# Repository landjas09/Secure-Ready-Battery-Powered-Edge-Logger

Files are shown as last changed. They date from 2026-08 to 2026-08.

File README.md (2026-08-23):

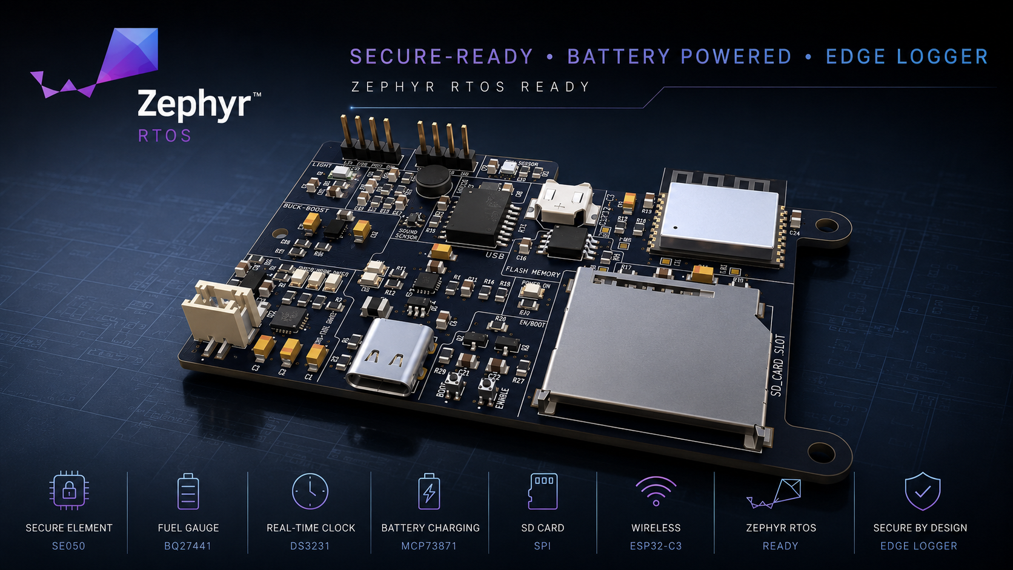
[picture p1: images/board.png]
ESP32-C3 Secure Edge Logger — assembled board


# Secure-Ready Battery-Powered Edge Logger

A custom ESP32-C3 hardware/firmware platform, developed across two revisions — from a general-purpose IoT sensor board into a battery-aware, timestamped, secure-ready edge data logger. Designed end-to-end in KiCad, ported to Zephyr RTOS.
This repository contains the full hardware design (schematics, PCB layout, BOM) for both revisions.

---

## Overview

The project began as the **IoT Development Board** (**Rev 1**) — a general-purpose ESP32-C3 sensor/data-logging platform: WiFi/BLE connectivity, environmental and ambient-light sensing, audio capture, local storage, and LiPo charging on a single compact PCB.

**Rev 2, the Secure-Ready Battery-Powered Edge Logger**, evolved that platform with a regulated buck-boost power stage holding 3.3V across the full LiPo discharge range, a battery fuel gauge with Kelvin current sensing, a battery-backed real-time clock for offline timestamping, and a hardware secure element for protected device identity and cryptographic key storage. The name change is deliberate, not cosmetic — it reflects the shift from a general-purpose development board to a system built around a specific mission: unattended, battery-aware, timestamped, secure-ready edge logging.

Both revisions share the same core sensing/storage/connectivity architecture; Rev 2 adds the hardware needed to take the board from *prototype* toward *deployable product*.

---

## Repository Structure

```
├── hardware/
│   ├── rev1/                     # IoT Development Board (original revision)
│   │   ├── README.md             # Full hardware documentation for Rev 1
│   │   └── ...                   # KiCad project, BOM, libraries
│   │
│   └── rev2/                     # Secure-Ready Battery-Powered Edge Logger (current revision)
│       ├── README.md             # Full hardware documentation for Rev 2
│       └── ...                   # KiCad project, BOM, libraries
│

│
└── README.md                     # This file
```

> Each revision is self-contained — its own KiCad project, its own Gerbers/BOM, and its own README with full component-level documentation, block diagrams, and design notes. Start here for the high-level picture, then go to the revision folder for detail.

---

## Hardware Revisions at a Glance

| | Rev 1 — IoT Development Board | Rev 2 — Secure Edge Logger |
|---|---|---|
| MCU | ESP32-C3-WROOM-02-H4 | ESP32-C3-WROOM-02-H4 |
| Power regulation | LM1117-3.3 linear regulator | TPS63802 buck-boost (regulated 3.3V across full LiPo range) |
| Battery charging | MCP73871 (charge + power-path) | MCP73871 (unchanged) |
| Battery state monitoring | Charge-status LEDs only | + BQ27441-G1A fuel gauge, 10mΩ Kelvin current sensing |
| Timekeeping | None (network time only) | + DS3231SN battery-backed RTC |
| Security | None | + NXP EdgeLock SE050E2 secure element |
| Storage | microSD + W25Q32 SPI NOR flash | microSD + W25Q32 SPI NOR flash (unchanged) |
| Sensing | BME280, TEMT6000X01, mic + MAX4466 preamp | Unchanged |
| Connectivity | USB-C, CP2102N USB-UART, OLED I²C header | Unchanged |
| Firmware target | Zephyr RTOS | Zephyr RTOS |

Full rationale for each Rev 2 change — including the buck-boost layout, Kelvin sensing wiring, and shared I²C bus considerations across five devices — is documented in [`hardware/rev2_secure-edge-logger/README.md`](hardware/rev2_secure-edge-logger/README.md).

---

## Design Evolution: The Engineering Behind Rev 1 → Rev 2

Rev 1 answered a narrower question: *can this sensing/connectivity architecture work on a single ESP32-C3 board?* It did — but running it as something closer to an actual field-deployed logger, rather than a bench prototype, surfaced four real limitations that Rev 1's architecture had no answer for. Rev 2 exists specifically to close those four gaps.

**1. The power rail wasn't guaranteed across the battery's actual operating range.**
The LM1117 is a linear regulator — it can only step *down*, and needs a few hundred millivolts of headroom above 3.3V to stay in regulation. A single-cell LiPo spends a meaningful portion of its discharge curve at or below that threshold, well before the cell is actually empty. In practice, that meant the system rail could sag or brown out with real battery capacity still remaining — the board would report "low battery" behavior driven by the regulator's limits, not the battery's. The **TPS63802 buck-boost** converter can step the rail up *or* down as needed, holding a stable 3.3V across the LiPo's full discharge range. The trade-off is real: an inductor-based switching regulator is a more complex layout than a 3-pin LDO (switching-node placement, input/output capacitor proximity), but it removes an artificial ceiling on usable battery capacity.

**2. Battery state was inferred, not measured.**
Rev 1's only battery-state signal was the MCP73871's charge-status LEDs — charging, charged, or power-good. That tells you the *charger's* state, not the battery's: no state-of-charge percentage, no remaining runtime estimate, no visibility into battery health over repeated cycles. For a device meant to log unattended in the field, "the LED is off" isn't useful data. The **BQ27441-G1A fuel gauge**, paired with a 10mΩ Kelvin-sensed shunt for accurate current measurement, gives the firmware real coulomb-counted state-of-charge and capacity data — the difference between guessing how much runtime is left and actually knowing.

**3. Timestamps depended on the network being present, and couldn't survive a real power interruption.**
The ESP32-C3 does have an internal RTC timer, and it runs independently of WiFi — but it has two limitations that make it unsuitable as the sole time source for an offline logger. First, it has no absolute time reference of its own; it only counts elapsed ticks, so it needs to be told the actual date/time at least once, which in Rev 1 meant NTP over WiFi. Second, and more importantly, it has no dedicated backup power domain — it's powered from the same rail as the rest of the chip, so a genuine power interruption (battery disconnected, fully depleted) resets it, and any subsequent logging either loses accurate timestamping or needs a full resync before it can be trusted again. That's a direct conflict with the point of an edge logger, which by definition needs to keep working — and keep accurate time — when disconnected or power-cycled. The **DS3231SN**, with its own dedicated backup supply, keeps ticking through main-power interruptions entirely independently of the ESP32-C3 and of network availability — log integrity no longer depends on the device staying connected or staying powered.

**4. There was no way to prove a device's identity, or protect anything it might need to keep secret.**
Rev 1 had no mechanism for device authentication at all. Any private key or credential would have had to live in the ESP32-C3's own flash — readable by anyone who can extract the chip's contents, meaning a physically compromised device could be cloned or impersonated with no way to detect it. The **SE050E2 secure element** generates and stores keys internally and performs signing/crypto operations without ever exposing key material to the application processor. This is explicitly a *hardware readiness* change, not a finished feature — the chip makes protected device identity possible; actual authentication behavior still has to be implemented and provisioned at the firmware level.

Taken together, Rev 1 — the **IoT Development Board** — validated *that the concept works*. Rev 2 — the **Secure-Ready Battery-Powered Edge Logger** — is the set of changes needed to start asking whether it could actually be *trusted and deployed*: accurate power delivery, real battery visibility, time integrity without a network, and a hardware root of trust. The rename reflects that shift, from a general platform to a system built for a specific job.

---

## Firmware

Both revisions target a common **Zephyr RTOS** board port (`iot_sensor_node_esp32c3`), built from scratch rather than as an overlay on an existing Espressif reference board — the SoC layer is inherited from Zephyr's existing ESP32-C3 support, with Devicetree, pinctrl, and Kconfig scoped to this board's actual hardware.

See [`zephyr/README.md`](https://github.com/landjas09/Zephyr-RTOS-Port/blob/db37eb44f9d1a81693981f7a8ff599a05c521f56/README.md) for the full board architecture, peripheral integration (I²C, SPI, ADC, UART, GPIO), debugging/OpenOCD setup, and the specific integration issues encountered and resolved during the port.

---

## Design Tools

- **Schematic capture & PCB layout:** KiCad 10
- **Electrical/design verification:** KiCad ERC & DRC
- **Firmware / board support:** Zephyr RTOS
- **Secure-element middleware:** NXP Plug & Trust (SE050E2)
- **Hardware configuration:** Silicon Labs Simplicity Studio / Xpress Configurator

---

## Where to Go Next

- **New to the project?** Start with [`hardware/rev1_iot-development-board/README.md`](hardware/rev1_iot-development-board/README.md) for the original, simpler architecture.
- **Interested in the current hardware?** Go to [`hardware/rev2_secure-edge-logger/README.md`](hardware/rev2_secure-edge-logger/README.md) for the full secure edge-logger design.
- **Interested in the firmware/RTOS side?** Go to [`zephyr/README.md`](https://github.com/landjas09/Zephyr-RTOS-Port/blob/db37eb44f9d1a81693981f7a8ff599a05c521f56/README.md) for the board port documentation.

---

## Acknowledgments

Board design informed by manufacturer reference designs and application notes from Espressif, Microchip, Texas Instruments, NXP, Analog Devices/Maxim, Silicon Labs, Bosch Sensortec, Winbond, and the Zephyr Project.

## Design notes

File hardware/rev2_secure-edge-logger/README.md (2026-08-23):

# Secure-Ready Battery-Powered Edge Logger — ESP32-C3

A custom-designed battery-powered edge logging platform built around the **ESP32-C3-WROOM-02**, evolved from the original IoT Development Board into a more complete embedded system with persistent timekeeping, hardware-backed security, battery-state monitoring, regulated battery operation, local storage, environmental sensing, ambient light sensing, audio capture, and USB-C programming/debug support. Designed end-to-end in **KiCad 10**, from schematic capture through PCB layout and routing.

---

## Overview

This board is a **secure-ready, battery-powered edge data-logging platform** — capable of acquiring sensor data, maintaining absolute time across power interruptions, storing data locally, monitoring its own battery state, and supporting hardware-protected device identity and cryptographic operations.

The ESP32-C3 remains the main processing and wireless controller, with critical system functions separated into dedicated hardware blocks: LiPo charging and power-path management (MCP73871), regulated buck-boost 3.3V conversion (TPS63802), battery fuel gauging (BQ27441-G1A), persistent real-time clock (DS3231SN), hardware-backed key storage (SE050E2), and local storage across microSD and external SPI flash.

**Applications:**
- Battery-powered environmental and acoustic edge logging
- Offline, timestamped sensor-data acquisition
- Secure-ready IoT edge nodes requiring protected device credentials
- Battery-aware embedded sensing platforms
- Zephyr RTOS hardware/driver development and validation

**Key design goals:**
- Reliable operation from both USB-C and a single-cell LiPo battery
- Regulated 3.3V operation across the full LiPo discharge range
- Battery charging, power-path management, and state-of-charge monitoring
- Persistent absolute time, independent of network availability
- Hardware support for protected device identity and cryptographic keys
- Local timestamped data logging through microSD and external SPI flash
- Environmental, ambient-light, and acoustic sensing
- USB-to-UART programming/debugging without an external serial adapter
- Shared I²C expansion with an external OLED header

---

## Block Diagram

```mermaid
flowchart LR
    USB[USB-C Connector<br/>SS-52400-002] --> ESD[ESD Protection<br/>USBLC6-2SC6]
    USB --> CHG[LiPo Charger / Power Path<br/>MCP73871-2CAI_ML]
    ESD --> UART[USB-UART Bridge<br/>CP2102N-Axx-xQFN20]
    UART <--> MCU[ESP32-C3-WROOM-02-H4]

    CHG --> REG[3.3V Buck-Boost<br/>TPS63802]
    REG --> MCU
    CHG --> LED1[Charge Status LEDs<br/>PG / STAT1 / STAT2]

    CHG <--> SHUNT[10 mΩ Kelvin Shunt]
    SHUNT <--> BAT[JST 1S LiPo Battery Connector]
    SHUNT --> GAUGE[BQ27441-G1A<br/>Fuel Gauge]
    BAT --> GAUGE

    MCU <-->|I2C| BME[BME280<br/>Temperature + Humidity + Pressure]
    MCU <-->|I2C| RTC[DS3231SN<br/>Battery-Backed RTC]
    MCU <-->|I2C| SE[SE050E2<br/>Secure Element]
    MCU <-->|I2C| GAUGE
    MCU <-->|I2C| OLED[OLED Display Header]

    MCU <-->|ADC| LDR[TEMT6000X01<br/>Ambient Light]
    MCU <-->|ADC| MIC[CMC-5042PF-AC + MAX4466EXK<br/>Microphone + Preamplifier]

    MCU <-->|SPI| FLASH[W25Q32JVSSIQ<br/>External SPI NOR Flash]
    MCU <-->|SPI| SD[GSD090012SEU<br/>microSD Card]

    RTC --> RTCBAT[RTC Backup Battery]

    MCU --> BOOT[BOOT / EN Buttons]
    MCU --> GPIO[GPIO18 / GPIO19 Breakout]
```

---

## Hardware Overview

### Power & Battery Management
| Component | Part Number | Function |
|---|---|---|
| USB-C Connector | SS-52400-002 | Main external power/data input |
| ESD Protection | USBLC6-2SC6 | Protects USB D+/D- from ESD transients |
| LiPo Charger / Power Path | MCP73871-2CAI_ML | Single-cell Li-Ion/LiPo charging and load-sharing/power-path management |
| 3.3V Regulator | TPS63802 | Buck-boost conversion for regulated 3.3V operation across the variable battery rail |
| Fuel Gauge | BQ27441-G1A | Battery voltage/current, state-of-charge, remaining-capacity, and health estimation |
| Current-Sense Resistor | 10 mΩ, 4-terminal Kelvin shunt | High-side charge/discharge current measurement for the BQ27441 |
| Battery Connector | JST 2-pin | Single-cell LiPo connection |
| Status Indicators | LED x3 | MCP73871 charging / charge-complete / power-good indication |

The MCP73871 controls the USB/battery power path exactly as in Rev 1 — powering the system while charging over USB, and switching seamlessly to battery when USB is removed.

The original **LM1117-3.3 linear regulator was replaced with a TPS63802 buck-boost converter**, since a single-cell LiPo spends most of its discharge curve below 3.3V toward the low end of its range — a linear regulator alone can't hold 3.3V once the input drops below it. The buck-boost stage keeps the 3.3V rail regulated whether the battery sits above or below that threshold.

The BQ27441-G1A measures charge/discharge current through a dedicated 10 mΩ Kelvin shunt inserted between the battery and the MCP73871's VBAT side, with dedicated SRP/SRN sense connections routed directly to the shunt's sense terminals to minimize measurement error.

### Timekeeping & Hardware Security
| Component | Part Number | Interface | Function |
|---|---|---|---|
| Real-Time Clock | DS3231SN | I²C | Battery-backed absolute time for timestamped logging |
| Secure Element | NXP EdgeLock SE050E2 | I²C | Hardware-protected key storage, device identity, signing, and cryptographic operations |

The DS3231SN provides absolute time independent of WiFi/network availability, retaining time through main-power interruptions via its own backup supply. Its **INT/SQW** output connects to **ESP32-C3 GPIO8** for alarm/square-wave functionality.

The SE050E2 provides the hardware foundation for a device root of trust — generating and storing private keys internally and performing cryptographic operations without ever exposing key material to the ESP32 application. Its presence makes the platform *secure-ready*; actual authentication/TLS/signing behavior still needs to be implemented at the firmware level.

### Core & Connectivity
| Component | Part Number | Function |
|---|---|---|
| MCU | ESP32-C3-WROOM-02-H4 | RISC-V, WiFi + BLE, main system controller |
| USB-UART Bridge | CP2102N-Axx-xQFN20 | USB-to-serial for programming/debugging |
| Flash Memory | W25Q32JVSSIQ | 32Mbit external SPI flash (firmware/config storage) |
| SD Card Socket | GSD090012SEU | microSD card slot (bulk data storage: logs, audio, images) |

Programming and debugging run over native USB via the CP2102N — USB-C → CP2102N → UART0 — with manual **BOOT** and **EN** pushbuttons as a direct hardware fallback.

### Sensors
| Component | Part Number | Interface | Function |
|---|---|---|---|
| Environmental Sensor | BME280 | I²C | Temperature, humidity, and barometric pressure |
| Ambient Light Sensor | TEMT6000X01 | Analog (ADC) | Ambient light intensity |
| Microphone Capsule | CMC-5042PF-AC | Analog | Electret condenser microphone |
| Mic Preamplifier | MAX4466EXK+T | Analog (ADC) | Adjustable-gain (25x–125x) microphone amplifier |

### User Interface / Expansion
- **BOOT** and **EN** pushbuttons for manual firmware flashing / reset
- **OLED display header** on the shared I²C bus
- **GPIO18 / GPIO19 breakout**, remaining available for alternate functions such as native USB/JTAG when not assigned by the application
- **GPIO8 is no longer spare** — it is now assigned to the DS3231SN's `INT/SQW` signal

---

## Shared Bus Architecture

**SPI bus** (microSD card + external SPI NOR flash, shared MOSI/MISO/SCLK, independent CS lines):
```
ESP32 MOSI ──┬──▶ microSD MOSI
             └──▶ W25Q32 MOSI

ESP32 MISO ──┬──◀ microSD MISO
             └──◀ W25Q32 MISO

ESP32 SCLK ──┬──▶ microSD SCLK
             └──▶ W25Q32 SCLK

ESP32 GPIO5  ───▶ microSD CS
ESP32 GPIO10 ───▶ W25Q32 CS
```

**I²C bus** (BME280, OLED header, DS3231SN, BQ27441-G1A, and SE050E2 — all sharing one SDA/SCL bus):
```
ESP32 GPIO4 / SDA ──┬── BME280
                    ├── OLED header
                    ├── DS3231SN
                    ├── BQ27441-G1A
                    └── SE050E2

ESP32 GPIO3 / SCL ──┬── BME280
                    ├── OLED header
                    ├── DS3231SN
                    ├── BQ27441-G1A
                    └── SE050E2
```

The bus uses a single shared pull-up network located near the BME280 — since every device sits on the same SDA/SCL nets, all five devices share the same pull-up pair rather than each getting its own. Routing is primarily linear, with a short branch/stub to the SE050E2. Bus speed is currently configured conservatively in the Zephyr board definition.

---

## Design Tools

- **Schematic capture & PCB layout:** KiCad 10
- **Simulation/verification:** KiCad ERC & DRC (Electrical Rules Checker / Design Rules Checker)
- **Firmware / board support:** Zephyr RTOS
- **Secure-element middleware:** NXP Plug & Trust, for SE050E2
- **Hardware config tools:** Silicon Labs Simplicity Studio / Xpress Configurator (for one-time CP2102N GPIO/TXT-RXT configuration)

The Zephyr board port was updated for the Rev 2 hardware to add: DS3231 RTC integration, BQ27441 fuel-gauge integration through Zephyr's sensor subsystem, SE050 I²C transport mapping for NXP Plug & Trust, and GPIO8 allocation for the RTC's `INT/SQW` line — alongside the existing BME280, ADC, SPI NOR, microSD, UART, and GPIO support carried over from Rev 1.

---

## Repository Structure

This is a native **KiCad 10** hierarchical project — keep the main project file, root schematic, PCB file, and every child schematic sheet together so the hierarchy resolves correctly when cloned.

```
├── rev2-secure-edge-logger.kicad_pro   # Main KiCad project file
├── rev2-secure-edge-logger.kicad_sch   # Root schematic sheet
├── rev2-secure-edge-logger.kicad_pcb   # PCB layout
│
├── ESP32-C3-02.kicad_sch               # Sub-sheet: MCU + core connectivity
├── sensors.kicad_sch                   # Sub-sheet: BME280, light sensor, mic/amp
├── userInterface.kicad_sch             # Sub-sheet: BOOT/EN buttons, OLED header, breakout
│
├── Libraries/                          # Custom footprints, symbols, and 3D models
├── BOM.csv                             # Bill of materials
├── fp-lib-table                        # Footprint library table
├── sym-lib-table                       # Symbol library table
```

> Lock files (`*.lck`), `.history/`, and `.git/` are local/version-control housekeeping and not part of the design itself.

---

## Known Issues & Design Notes

- **Power architecture change:** the original LM1117-3.3 LDO was replaced with a TPS63802 buck-boost converter, since the LiPo's voltage range crosses above and below 3.3V — a linear regulator alone can't hold the rail once the battery drops below it.
- **Buck-boost layout:** TPS63802 input/output capacitors and the 0.47µH inductor are placed close to the regulator, with short/wide switching-current paths, and the feedback network routed away from the switching nodes.
- **Fuel-gauge measurement:** BQ27441 SRP/SRN use Kelvin connections directly to the 10mΩ four-terminal shunt; battery-voltage sensing is taken from the battery side of the shunt.
- **Charging vs. gauging are separate concerns:** the MCP73871's status outputs (PG, STAT1, STAT2) indicate *charger* state, not battery percentage — state-of-charge and remaining-capacity estimation is handled entirely by the BQ27441.
- **I²C pull-ups:** the entire bus (5 devices) uses one shared pull-up pair. Any future external module added to the OLED header needs to account for this — extra pull-ups on that module would combine in parallel and lower the effective bus resistance.
- **RTC interrupt:** DS3231SN's `INT/SQW` is open-drain, connected to GPIO8 — pull-up behavior needs to match the final hardware/firmware configuration.
- **Secure element scope:** SE050E2 provides the hardware capability for key storage and cryptographic operations, but the board should only be described as "cryptographically secured" once firmware actually provisions and uses those functions — the chip alone doesn't make the system secure.
- **GPIO5 / ADC2 conflict** (carried over from Rev 1): GPIO5 is the ESP32-C3's only ADC2 channel and is unreliable while WiFi is active. Analog signals (microphone, light sensor) use ADC1 pins instead; GPIO5 itself is used here purely as a digital SPI chip-select, where this limitation doesn't apply.
- **CP2102N TXT/RXT indicator LEDs:** default to plain GPIO mode from the factory and require explicit configuration via Silicon Labs' Xpress Configurator to enable the TXT/RXT alternate function.
- **SD card DAT3/CS line** requires a pull-up resistor so the card initializes into SPI mode rather than native SD mode at power-up.

---

## Planned Additions

- **Enclosure design (SolidWorks)** — case built around the Rev 2 board's exported KiCad STEP file, with cutouts for the USB-C port, BOOT/EN buttons, status LEDs, SD card slot, and a light-transmissive window over the ambient light sensor.

---

## Evolution from Rev 1

**Rev 1 — IoT Development Board** established the base platform: ESP32-C3 WiFi/BLE processing, BME280 environmental sensing, ambient-light and acoustic sensing, microSD + SPI NOR storage, LiPo charging and power-path management, USB-UART programming/debugging, OLED/GPIO expansion, and the initial custom Zephyr board port.

**Rev 2** extends that base around four system-level additions:

| Requirement | Change |
|---|---|
| Persistent timekeeping | Added DS3231SN with backup supply and RTC alarm/square-wave on GPIO8 |
| Hardware-backed security | Added NXP EdgeLock SE050E2 for protected device identity, key storage, and signing |
| Battery-state observability | Added BQ27441-G1A with 10mΩ Kelvin current sensing for voltage/current/SOC/health |
| Battery-range power regulation | Replaced LM1117-3.3 with TPS63802 buck-boost to hold 3.3V across the full LiPo range |

The result is no longer a general-purpose IoT development board — the architecture is now built around autonomous, timestamped, battery-aware logging with hardware security readiness built in from the start.

---

## Acknowledgments

Board design informed by manufacturer reference designs and application notes from Espressif, Microchip, Texas Instruments, NXP, Analog Devices/Maxim, Silicon Labs, Bosch Sensortec, Winbond, and the Zephyr Project.

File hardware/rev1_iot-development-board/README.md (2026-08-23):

# Custom IoT Development Board — ESP32-C3

A custom-designed IoT development board built around the **ESP32-C3-WROOM-02**, featuring integrated LiPo battery charging, environmental sensing, ambient light sensing, audio capture, on-board storage (flash + SD card), and a USB-C interface with full USB-to-UART programming support. Designed end-to-end in **KiCad 10**, from schematic capture through PCB layout and routing.

---

## Overview

This board was designed as a general-purpose sensor/data-logging platform for IoT applications — combining wireless connectivity (WiFi/BLE via the ESP32-C3), multiple onboard sensors, local storage, and rechargeable battery power into a single compact PCB.

## Aplications
- IoT edge devices for environmental monitoring.
- Battery-powered data logging systems.
- Prototyping platform for ESP32-based projects.

**Key design goals:**
- Fully USB-C powered and rechargeable (no external charger required)
- Onboard environmental, light, and audio sensing
- Local data logging via SD card, with dedicated flash for firmware/configuration
- Standard USB-to-UART programming/debugging, no external programmer needed
- Expandable via an I²C OLED connector and a breakout header for spare GPIOs

---

## Block Diagram

```mermaid
flowchart LR
    USB[USB-C Connector<br/>SS-52400-002] --> ESD[ESD Protection<br/>USBLC6-2SC6]
    USB --> CHG[LiPo Charger<br/>MCP73871-2CAI_ML]
    ESD --> UART[USB-UART Bridge<br/>CP2102N-Axx-xQFN20]
    UART <--> MCU[ESP32-C3-WROOM-02-H4]

    CHG --> BAT[JST LiPo Battery Connector]
    CHG --> REG[3.3V Regulator<br/>LM1117MPX-3.3]
    REG --> MCU
    CHG --> LED1[Charge Status LEDs]

    MCU <-->|I2C| BME[BME280<br/>Humidity + Pressure]
    MCU <-->|ADC| LDR[TEMT6000X01<br/>Ambient Light]
    MCU <-->|ADC| MIC[CMC-5042PF-AC + MAX4466EXK<br/>Mic + Amplifier]
    MCU <-->|SPI| FLASH[W25Q32JVSSIQ<br/>External Flash]
    MCU <-->|SPI| SD[GSD090012SEU<br/>microSD Card]
    MCU <-->|I2C| OLED[OLED Display Header]

    MCU --> BOOT[BOOT / EN Buttons]
    MCU --> GPIO[Spare GPIO Breakout]
```

---

## Hardware Overview

### Power Subsystem
| Component | Part Number | Function |
|---|---|---|
| USB-C Connector | SS-52400-002 | Main power/data input |
| ESD Protection | USBLC6-2SC6 | Protects USB D+/D- from ESD transients |
| LiPo Charger IC | MCP73871-2CAI_ML | Single-cell Li-Ion/LiPo charge management with power-path support |
| Voltage Regulator | LM1117MPX-3.3_NOPB | Regulates system rail to 3.3V |
| Battery Connector | JST 2-pin | Single-cell LiPo battery input |
| Status Indicators | LED x3 | Charging / Charged / Power-Good status |

The MCP73871's integrated power-path management allows the board to run directly from USB power while simultaneously charging the battery, and seamlessly switches to battery power when USB is disconnected — with no interruption to the system rail.

### Core & Connectivity
| Component | Part Number | Function |
|---|---|---|
| MCU | ESP32-C3-WROOM-02-H4 | RISC-V, WiFi + BLE, main system controller |
| USB-UART Bridge | CP2102N-Axx-xQFN20 | USB-to-serial for programming/debugging |
| Flash Memory | W25Q32JVSSIQ | 32Mbit external SPI flash (firmware/config storage) |
| SD Card Socket | GSD090012SEU | microSD card slot (bulk data storage: logs, audio, images) |

Programming and debugging are handled over native USB via the CP2102N, with automatic bootloader entry through a DTR/RTS-driven transistor reset circuit, plus manual BOOT and EN pushbuttons as a hardware fallback.

### Sensors
| Component | Part Number | Interface | Function |
|---|---|---|---|
| Environmental Sensor | BME280 | I²C | Humidity, barometric pressure, temperature |
| Ambient Light Sensor | TEMT6000X01 | Analog (ADC) | Ambient light intensity |
| Microphone Capsule | CMC-5042PF-AC | Analog | Electret condenser microphone |
| Mic Preamplifier | MAX4466EXK+T | Analog (ADC) | Adjustable-gain (25x–125x) microphone amplifier |

### User Interface / Expansion
- **BOOT** and **EN** pushbuttons for manual firmware flashing / reset
- **OLED display header** (I²C, 4-pin) for an external SSD1306-style display
- **Breakout header** exposing spare GPIOs (GPIO8, GPIO18, GPIO19) plus 3.3V/GND for future expansion

---

## Shared Bus Architecture

**SPI bus** (SD card + external flash, daisy-chained MOSI/MISO/SCLK, independent CS lines):
```
ESP32 MOSI ──┬──▶ SD Card MOSI ──▶ Flash MOSI
ESP32 MISO ──┼──◀ SD Card MISO ──◀ Flash MISO
ESP32 SCLK ──┴──▶ SD Card SCLK ──▶ Flash SCLK
ESP32 CS1  ─────▶ SD Card CS (dedicated)
ESP32 CS2  ─────▶ Flash CS (dedicated)
```

**I²C bus** (BME280 + OLED header, shared SDA/SCL with pull-ups):
```
ESP32 SDA ──┬──▶ BME280 SDA
            └──▶ OLED SDA
ESP32 SCL ──┬──▶ BME280 SCL
            └──▶ OLED SCL
```

---

## Design Tools

- **Schematic capture & PCB layout:** KiCad 10
- **Simulation/verification:** KiCad ERC & DRC (Electrical Rules Checker / Design Rules Checker)
- **Firmware:** successfully migrated to **Zephyr RTOS**
- **Hardware config tools:** Silicon Labs Simplicity Studio (for one-time CP2102N GPIO/TXT-RXT configuration)

---

## Repository Structure

This is a native **KiCad 10** project — the schematic is split hierarchically across multiple sheets, with sensors and user-interface elements broken out into their own sub-sheet files for readability.

```
├── IOT DEV BOARD.kicad_pro       # Main KiCad project file
├── IOT DEV BOARD.kicad_sch       # Root schematic sheet
├── IOT DEV BOARD.kicad_pcb       # PCB layout
├── ESP32-C3-02.kicad_sch         # Sub-sheet: MCU + core connectivity
├── sensors.kicad_sch             # Sub-sheet: BME280, light sensor, mic/amp
├── userInterface.kicad_sch       # Sub-sheet: BOOT/EN buttons, OLED header, breakout
│
├── ESP32_IOT_BOARD_GERBER/       # Exported Gerber/drill files for fabrication
├── Libraries/                    # Custom footprints and symbols
├── BOM.csv                       # Bill of materials
├── fp-lib-table                  # Footprint library table
├── sym-lib-table                 # Symbol library table
└── output.json                   # Exported netlist/data
```

> Lock files (`*.lck`), `.history/`, and `.git/` are local/version-control housekeeping and not part of the design itself.

---

## Known Issues & Design Notes

- **GPIO5 / ADC2 conflict:** GPIO5 is the ESP32-C3's only ADC2 channel, and ADC2 is unreliable while WiFi is active (and affected by a known silicon errata on some chip revisions). Analog signals (e.g. microphone, light sensor) must use **ADC1 pins (GPIO0–GPIO4)** instead.
- **CP2102N TXT/RXT indicator LEDs:** these pins default to plain GPIO mode from the factory and do **not** blink out of the box — they must be explicitly configured via Silicon Labs' **Xpress Configurator** (Simplicity Studio) to enable the TXT/RXT alternate function.
- **CP2102N QFN20 package** does not expose a physical DTR pin — DTR emulation for the auto-reset circuit is handled via a reconfigured spare GPIO, not a dedicated pin.
- **SD card DAT3/CS line** requires a pull-up resistor to guarantee the card boots into SPI mode rather than native SD mode at power-up.

---

## Planned Additions

- **DS3231SN** real-time clock (I²C) for accurate timestamping of logged sensor data, independent of network time availability.
- **Enclosure design (SolidWorks)** — case built around the board's exported KiCad STEP file, with cutouts for the USB-C port, BOOT/EN buttons, status LEDs, SD card slot, and a light-transmissive window over the ambient light sensor.

---

## Acknowledgments

Board design informed by manufacturer reference designs and application notes from Microchip, Silicon Labs, Espressif, and Winbond.

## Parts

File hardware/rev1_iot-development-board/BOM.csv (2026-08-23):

Reference | Qty | Value | Footprint | MANUFACTURER | Description
VR1 | 1 | LM1117MPX-3.3_NOPB | ESP32Footprints:VREG_LM1117MPX-3.3 | Texas Instruments | 800-mA 15-V linear voltage regulator
U7 | 1 | MAX4466EXK | ESP32Footprints:SOT65P210X110-5N |  | Amplifier IC 1-Channel (Mono) Class AB SC-70-5
U6 | 1 | BME280 | ESP32Footprints:PSON65P250X250X100-8N |  | Board Mount Humidity Sensors MEMS humidity, pressure and temperature sensor
U5 | 1 | USBLC6-2SC6 | Package_TO_SOT_SMD:SOT-23-6 |  | Very low capacitance ESD protection diode, 2 data-line, SOT-23-6
U4 | 1 | W25Q32JVSSIQ | ESP32Footprints:SOIC127P790X216-8N |  | FLASH - NOR Memory IC 32Mb (4M x 8) SPI - Quad I/O 133 MHz 8-SOIC
U3 | 1 | ESP32-C3-WROOM-02-H4 | ESP32Footprints:MODULE_ESP32-C3-WROOM-02-H4 |  | WiFi Modules (802.11) (Engineering Samples) SMD module, ESP32-C3, 4MB SPI flash, PCB antenna, -40 C +105 C
U2 | 1 | CP2102N-Axx-xQFN20 | Package_DFN_QFN:SiliconLabs_QFN-20-1EP_3x3mm_P0.5mm_EP1.8x1.8mm |  | USB to UART master bridge, QFN-20
U1 | 1 | MCP73871-2CAI_ML | ESP32Footprints:QFN50P400X400X100-21N | Microchip Corp. | Microchip MCP73871-2CAI/ML, Battery Charge Controller, 1000mA, 20-Pin QFN | Microchip Technology Inc. MCP73871-2CAI/ML
TP5 | 1 | TestCLK | TestPoint:TestPoint_Pad_1.0x1.0mm |  | test point
TP4 | 1 | TestCS | TestPoint:TestPoint_Pad_1.0x1.0mm |  | test point
TP3 | 1 | TestSD | TestPoint:TestPoint_Pad_1.0x1.0mm |  | test point
TP2 | 1 | TestMOSI | TestPoint:TestPoint_Pad_1.0x1.0mm |  | test point
TP1 | 1 | TestMISO | TestPoint:TestPoint_Pad_1.0x1.0mm |  | test point
S2 | 1 | ENABLE | TL3305AF260QG:SW_TL3305AF260QG | E-Switch | Tactile Switch SPST-NO Top Actuated Surface Mount
S1 | 1 | BOOT | TL3305AF260QG:SW_TL3305AF260QG | E-Switch | Tactile Switch SPST-NO Top Actuated Surface Mount
R25,R26 | 2 | 2k | Resistor_SMD:R_0805_2012Metric |  | Resistor
R23,R24 | 2 | 1M | Resistor_SMD:R_0805_2012Metric |  | Resistor
R22 | 1 | 10k | Resistor_SMD:R_0805_2012Metric |  | Resistor
R20,R21 | 2 | 4.7k | Resistor_SMD:R_0805_2012Metric |  | Resistor
R19 | 1 | 100K | Resistor_SMD:R_0805_2012Metric |  | Resistor
R15,R16,R17,R18 | 4 | 50 | Resistor_SMD:R_0805_2012Metric |  | Resistor
R14 | 1 | 47K5 | Resistor_SMD:R_0805_2012Metric |  | Resistor
R13 | 1 | 22K1 | Resistor_SMD:R_0805_2012Metric |  | Resistor
R7,R8,R9,R10,R11,R12 | 6 | 470 | Resistor_SMD:R_0805_2012Metric |  | Resistor
R6 | 1 | 20K | Resistor_SMD:R_0805_2012Metric |  | Resistor
R5 | 1 | 2K | Resistor_SMD:R_0805_2012Metric |  | Resistor
R3,R4 | 2 | 5K1 | Resistor_SMD:R_0805_2012Metric |  | Resistor
R2,R27,R28,R29,R30,R31 | 6 | 10K | Resistor_SMD:R_0805_2012Metric |  | Resistor
R1 | 1 | 1k | Resistor_SMD:R_0805_2012Metric |  | Resistor
Q2,Q3 | 2 | BC817 | Package_TO_SOT_SMD:SOT-23 |  | 0.8A Ic, 45V Vce, NPN Transistor, SOT-23
Q1 | 1 | TEMT6000X01 | ESP32Footprints:TRANS_TEMT6000X01 | VISHAY | Phototransistors 570nm Top View 1206 (3216 Metric)
MK1 | 1 | CMC-5042PF-AC | ESP32Footprints:CUI_CMC-5042PF-AC | CUI INC | 6.0 mm, Omnidirectional, PCB Mount, 2.0 Vdc, Electret Condenser Microphone
LED3 | 1 | LTST-C170TBKT | ESP32Footprints:LEDC2012X120N |  | LED,SMD,0805,Blue,28mcd,130deg
LED2,LED6 | 2 | LTST-C170GKT | ESP32Footprints:LEDC2012X120N |  | LED,SMD,0805,Green,6mcd,130deg Lite-On LTST-C170GKT, CHIPLED 0805 Series Green LED, 569 nm 2012 (0805), Rectangle Lens SMD package
LED1,LED4,LED5 | 3 | LTST-C170KRKT | ESP32Footprints:LEDC2012X120N |  | Standard LEDs - SMD Red Clear 631nm
J5 | 1 | Conn_01x05_Pin | Connector_PinHeader_2.54mm:PinHeader_1x05_P2.54mm_Vertical |  | Generic connector, single row, 01x05, script generated
J4 | 1 | Conn_01x04_Pin | Connector_PinHeader_2.54mm:PinHeader_1x04_P2.54mm_Vertical |  | Generic connector, single row, 01x04, script generated
J3 | 1 | GSD090012SEU | ESP32Footprints:AMPHENOL_GSD090012SEU | Amphenol | Micro SD and SD Card Sockets, Input Output Connectors, SD Socket,9 Position,SMT
J2 | 1 | B2B-PH-SM4-TB | ESP32Footprints:JST_B2B-PH-SM4-TB | JST | Connector Header Surface Mount 2 position 0.079 (2.00mm)
J1 | 1 | SS-52400-002 | ESP32Footprints:BELFUSE_SS-52400-002 | BelFuse | USB Type-C Connector | USB 3.1 | 1 Port | Right Angle Receptacle | Shielded | 0.039 in (1.00mm) PCB Thickness
F1 | 1 | 0ZCH0110AF2E | ESP32Footprints:FUSC3226X100N |  | 1210 SMT PPTC | 1.10 Ih | 16V
C24,C25 | 2 | 10n | Capacitor_SMD:C_0805_2012Metric |  | Unpolarized capacitor
C23 | 1 | 100n | Capacitor_SMD:C_0805_2012Metric |  | Unpolarized capacitor
C19 | 1 | 0.01u | Capacitor_SMD:C_0805_2012Metric |  | Unpolarized capacitor
C18 | 1 | 1u | Capacitor_SMD:C_0805_2012Metric |  | Unpolarized capacitor
C17 | 1 | 100p | Capacitor_SMD:C_0805_2012Metric |  | Unpolarized capacitor
C13 | 1 | 1Ou | ESP32Footprints:T491A |  | Unpolarized capacitor
C12 | 1 | 0.1U | Capacitor_SMD:C_0805_2012Metric |  | Unpolarized capacitor
C4,C6,C8,C9,C11,C14,C16,C20,C21,C22,C26 | 11 | 0.1u | Capacitor_SMD:C_0805_2012Metric |  | Unpolarized capacitor
C2,C3,C10 | 3 | 4.7u | ESP32Footprints:T491A |  | Unpolarized capacitor
C1,C5,C7,C15 | 4 | 10u | ESP32Footprints:T491A |  | Unpolarized capacitor

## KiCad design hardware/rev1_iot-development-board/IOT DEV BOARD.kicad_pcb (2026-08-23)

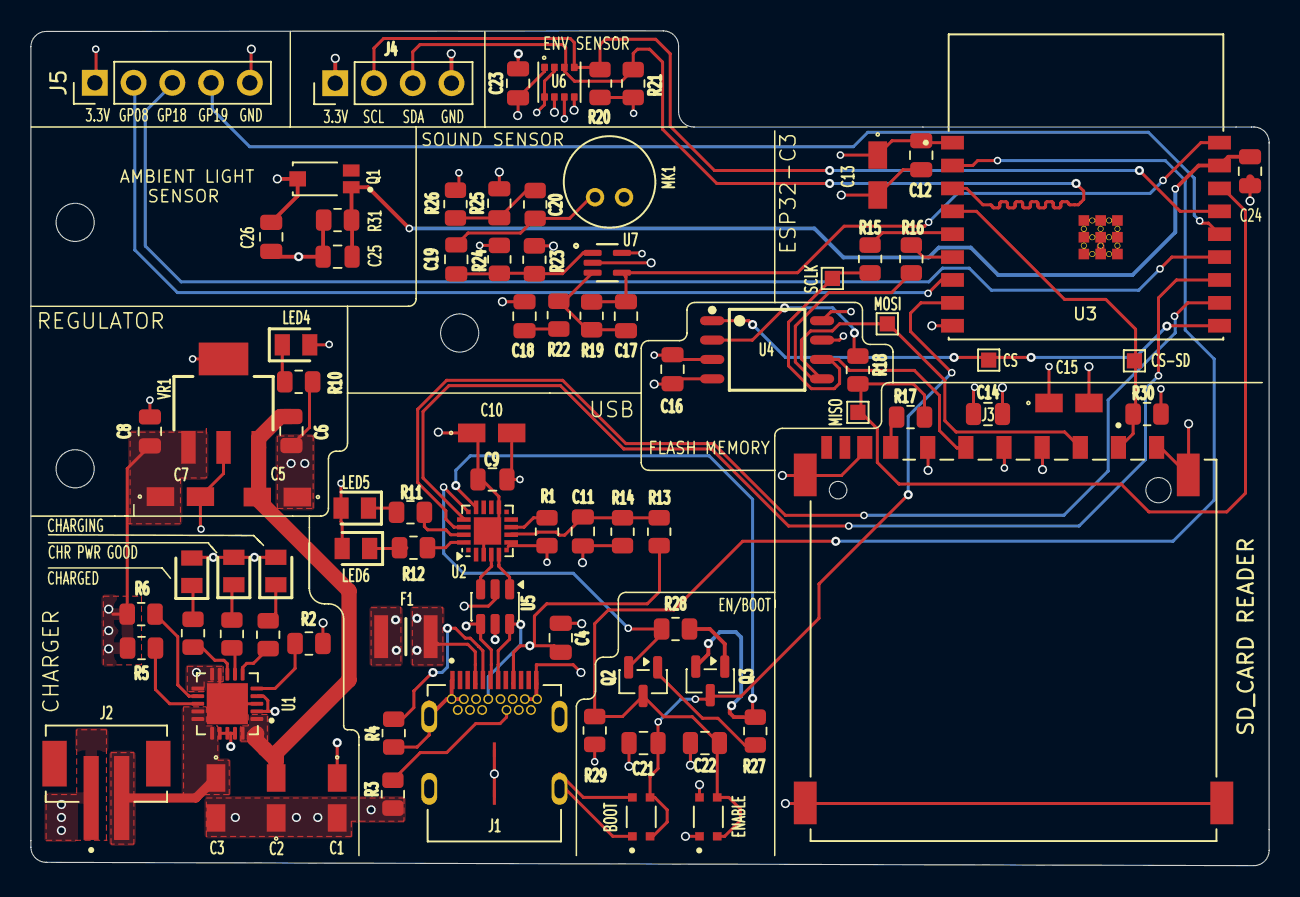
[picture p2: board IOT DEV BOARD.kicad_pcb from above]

Board: 4 copper layers, 81.2 x 54.7 mm, 91 parts (0 on the bottom side), 57 nets.

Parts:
BOOT: BOOT; SW_USLPT2819DT2TR
C1, C5, C7, C15: 10u; T491A
C2, C3, C10: 4.7u; T491A
C4, C6, C8, C9, C11, C14, C16, C20, C21, C22, C26: 0.1u; C_0805_2012Metric
C12: 0.1U; C_0805_2012Metric
C13: 1Ou; T491A
C17: 100p; C_0805_2012Metric
C18: 1u; C_0805_2012Metric
C19: 0.01u; C_0805_2012Metric
C23: 100n; C_0805_2012Metric
C24, C25: 10n; C_0805_2012Metric
CS: TestCS; TestPoint_Pad_1.0x1.0mm
CS-SD: TestSD; TestPoint_Pad_1.0x1.0mm
ENABLE: ENABLE; SW_USLPT2819DT2TR
F1: 0ZCH0110AF2E; FUSC3226X100N
J1: SS-52400-002; BELFUSE_SS-52400-002
J2: B2B-PH-SM4-TB; JST_B2B-PH-SM4-TB
J3: GSD090012SEU; AMPHENOL_GSD090012SEU
J4: Conn_01x04_Pin; PinHeader_1x04_P2.54mm_Vertical
J5: Conn_01x05_Pin; PinHeader_1x05_P2.54mm_Vertical
LED1, LED4, LED5: LTST-C170KRKT; LEDC2012X120N
LED2, LED6: LTST-C170GKT; LEDC2012X120N
LED3: LTST-C170TBKT; LEDC2012X120N
MH01, MH01#2, MH03: MountingHole_2.5mm
MISO: TestMISO; TestPoint_Pad_1.0x1.0mm
MK1: CMC-5042PF-AC; CUI_CMC-5042PF-AC
MOSI: TestMOSI; TestPoint_Pad_1.0x1.0mm
Q1: TEMT6000X01; TRANS_TEMT6000X01
Q2, Q3: BC817; SOT-23
R1: 1k; R_0805_2012Metric
R2, R27, R28, R29, R30, R31: 10K; R_0805_2012Metric
R3, R4: 5K1; R_0805_2012Metric
R5: 2K; R_0805_2012Metric
R6: 20K; R_0805_2012Metric
R7, R8, R9, R10, R11, R12: 470; R_0805_2012Metric
R13: 22K1; R_0805_2012Metric
R14: 47K5; R_0805_2012Metric
R15, R16, R17, R18: 50; R_0805_2012Metric
R19: 100K; R_0805_2012Metric
R20, R21: R; R_0805_2012Metric
R22: 10k; R_0805_2012Metric
R23, R24: 1M; R_0805_2012Metric
R25, R26: 2k; R_0805_2012Metric
SCLK: TestCLK; TestPoint_Pad_1.0x1.0mm
U1: MCP73871-2CAI_ML; QFN50P400X400X100-21N
U2: CP2102N-Axx-xQFN20; SiliconLabs_QFN-20-1EP_3x3mm_P0.5mm_EP1.8x1.8mm
U3: ESP32-C3-WROOM-02-H4; MODULE_ESP32-C3-WROOM-02-H4
U4: W25Q32JVSSIQ; SOIC127P790X216-8N
U5: USBLC6-2SC6; SOT-23-6
U6: BME280; PSON65P250X250X100-8N
U7: MAX4466EXK; SOT65P210X110-5N
VR1: LM1117MPX-3.3_NOPB; VREG_LM1117MPX-3.3

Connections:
+3.3V: C7.2, C8.2, C9.2, C10.2, C12.1, C13.1, C14.1, C15.1, C16.2, C23.2, C26.1, J3.4 (VDD1), J4.1, J5.1, LED4.2 (A), LED5.2 (A), LED6.2 (A), Q1.3, R1.1, R20.1, R21.1, R24.2, R26.2, R29.2, R30.1, U2.6 (VDD), U2.7 (VREGIN), U3.1 (3V3), U4.3 (~WP(IO2)), U4.7 (~HOLD/~RESET(IO3)), U4.8 (VCC), U6.2 (CSB), U6.6 (VDDIO), U6.8 (VDD), U7.5 (VCC), VR1.2 (VOUT_2), VR1.4 (VOUT_4)
+5V: C2.2, C5.2, C6.2, U1.1 (OUT), U1.20 (OUT), VR1.3 (VIN)
/+5V-USB: C1.1, F1.2, LED1.2 (A), LED2.2 (A), LED3.2 (A), U1.2 (VPCC), U1.4 (PROG2), U1.17 (CE), U1.18 (IN), U1.19 (IN)
/CHARGED: R9.1, U1.8 (STAT1/~LBO)
/CHARGING: R7.1, U1.6 (~PG)
/CHARGING-POWE-GOOD: R8.1, U1.7 (STAT2)
/ESP32-C3-02/BOOT: BOOT.3, BOOT.4, C21.1, Q3.3 (C), U3.8 (IO9)
/ESP32-C3-02/CS: CS.1 (1_1), U3.10 (IO10), U4.1 (~CS)
/ESP32-C3-02/CS-SD: CS-SD.1 (1_1), J3.1 (CD/DAT3), R30.2, U3.4 (IO5)
/ESP32-C3-02/DTS: Q3.2 (E), R27.1, U2.15 (~CTS)
/ESP32-C3-02/EN: C22.1, ENABLE.3, ENABLE.4, Q2.3 (C), R29.1, U3.2 (EN)
/ESP32-C3-02/GPIO08: J5.2, U3.7 (IO8)
/ESP32-C3-02/GPIO18: J5.3, U3.13 (IO18)
/ESP32-C3-02/GPIO19: J5.4, U3.14 (IO19)
/ESP32-C3-02/MIC_OUT: C17.2, R19.2, U3.18 (IO0), U7.4 (OUT)
/ESP32-C3-02/MISO_DO: MISO.1 (1_1), R17.2, R18.2, U3.16 (IO2)
/ESP32-C3-02/MOSI-DI: J3.2 (CMD), MOSI.1 (1_1), R16.2, U4.5 (DI(IO0))
/ESP32-C3-02/PHOTO-C: C24.1, C25.1, Q1.1, R31.1, U3.17 (IO1)
/ESP32-C3-02/RTS: Q2.2 (E), R28.1, U2.16 (~RTS)
/ESP32-C3-02/RX-TX: U2.17 (RXD), U3.12 (TXD)
/ESP32-C3-02/SCL: J4.2, R20.2, U3.15 (IO3), U6.4 (SCK)
/ESP32-C3-02/SCLK: J3.5 (CLK), R15.1, SCLK.1 (1_1), U4.6 (CLK)
/ESP32-C3-02/SDA: J4.3, R21.2, U3.3 (IO4), U6.3 (SDI)
/ESP32-C3-02/TX-RX: U2.18 (TXD), U3.11 (RXD)
/ESP32-C3-02/USB_D+: U2.4 (D+), U5.3 (I/O2)
/ESP32-C3-02/USB_D-: U2.5 (D-), U5.1 (I/O1)
/USB-DN: J1.A7 (DN1), J1.B7 (DN2), U5.6 (I/O1)
/USB-DP: J1.A6 (DP1), J1.B6 (DP2), U5.4 (I/O2)
/VBAT: C3.1, J2.2, U1.14 (VBAT), U1.15 (VBAT), U1.16 (VBAT_SENSE)
/VBUS: C4.2, F1.1, J1.A4 (VBUSA1), J1.A9 (VBUSA2), J1.B4 (VBUSB1), J1.B9 (VBUSB2), R13.2, U5.5 (VBUS)
GND: BOOT.1, BOOT.2, C1.2, C2.1, C3.2, C4.1, C5.1, C6.1, C7.1, C8.1, C9.1, C10.1, C11.1, C12.2, C13.2, C14.2, C15.2, C16.1, C18.1, C20.1, C21.2, C22.2, C23.1, C24.2, C25.2, C26.2, ENABLE.1, ENABLE.2, J1.A1 (GNDA1), J1.A12 (GNDA2), J1.B1 (GNDB1), J1.B12 (GNDB2), J1.G1 (GND/SHIELD), J1.G2 (GND/SHIELD), J1.G3 (GND/SHIELD), J1.G4 (GND/SHIELD), J1.S1 (GND/SHIELD), J1.S2 (GND/SHIELD), J1.S3 (GND/SHIELD), J1.S4 (GND/SHIELD), J2.1, J3.3 (VSS1), J3.6 (VSS2), J3.8 (DAT1), J3.9 (DAT2), J3.G1 (SHIELD_GND), J3.G2 (SHIELD_GND), J3.G3 (SHIELD_GND), J3.G4 (SHIELD_GND), J4.4, J5.5, MK1.GND, R2.2, R3.2, R4.2, R5.2, R6.2, R10.1, R14.1, R23.1, R31.2, U1.3 (SEL), U1.9 (~TE), U1.10 (VSS), U1.11 (VSS), U1.21 (VSS), U2.3 (GND), U2.12 (GND), U2.21 (GND), U3.9 (GND), U3.19 (GND), U3.20 (GND), U3.21 (GND), U3.22 (GND), U3.23 (GND), U3.24 (GND), U3.25 (GND), U3.26 (GND), U3.27 (GND), U3.28 (GND), U3.29 (GND), U3.30 (GND), U3.31 (GND), U3.32 (GND), U3.33 (GND), U3.34 (GND), U3.35 (GND), U3.36 (GND), U3.37 (GND), U3.38 (GND), U3.39 (GND), U4.4 (GND), U5.2 (GND), U6.1 (GND), U6.5 (SDO), U6.7 (GND), U7.2 (GND), VR1.1 (GND)
unnamed: C18.2, R22.1
unnamed: C19.2, MK1.OUT, R25.1
unnamed: C20.2, R25.2, R26.1
unnamed: J1.A5 (CC1), R4.1
unnamed: J1.B5 (CC2), R3.1
unnamed: J3.7 (DAT0), R17.1
unnamed: LED1.1 (K), R7.2
unnamed: LED2.1 (K), R9.2
unnamed: LED3.1 (K), R8.2
unnamed: LED4.1 (K), R10.2
unnamed: LED5.1 (K), R11.2
unnamed: LED6.1 (K), R12.2
unnamed: Q2.1 (B), R27.2
unnamed: Q3.1 (B), R28.2
unnamed: R5.1, U1.13 (PROG1)
unnamed: R6.1, U1.12 (PROG3)
unnamed: R2.1, U1.5 (THERM)
unnamed: C11.2, R13.1, R14.2, U2.8 (VBUS)
unnamed: R1.2, U2.9 (~RST)
unnamed: R11.1, U2.19 (~RXT/GPIO.3)
unnamed: R12.1, U2.20 (~TXT/GPIO.2)
unnamed: R15.2, U3.5 (IO6)
unnamed: R16.1, U3.6 (IO7)
unnamed: R18.1, U4.2 (DO(IO1))
unnamed: C19.1, R23.2, R24.1, U7.1 (IN+)
unnamed: C17.1, R19.1, R22.2, U7.3 (IN-)

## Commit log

2026-08-23 Rename IOT DEV BOARD.kicad_pcb to hardware/rev1_iot-development-board/IOT DEV BOARD.kicad_pcb
    [IOT DEV BOARD.kicad_pcb]
2026-08-23 Rename IOT DEV BOARD.kicad_pro to hardware/rev1_iot-development-board/IOT DEV BOARD.kicad_pro
2026-08-23 Rename IOT DEV BOARD.kicad_sch to hardware/rev1_iot-development-board/IOT DEV BOARD.kicad_sch
    [IOT DEV BOARD.kicad_sch]
